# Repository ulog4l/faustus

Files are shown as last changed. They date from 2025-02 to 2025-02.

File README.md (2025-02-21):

# faustus

32 key [hummingbird](https://github.com/PJE66/hummingbird) adjacent keyboard, also taking inspiration from its variations, such as the [zilpzalp](https://github.com/kilipan/zilpzalp) thumb keys\
also credits to [ergogen](ergogen.cache.works) for simplifying the key placement tremendously\
exclusively supports choc switches, is choc spaced\
exclusively supports the [MIAO](https://github.com/kilipan/miao) controller and [FAK firmware](https://github.com/semickolon/fak)

this keyboard essentially restores the middle column to a hummingbird, making it possible to not combo for these keys and ruin your muscle memory for all other keyboards\
this is made possible by the miao having additional IO pins, removing the 30 key limit of the xiao that is used in the hummingbird

this keyboard uses BAV70 diodes

this pcb has some mounting tabs meant to provide freedom in designing cases, but sticking adhesive feet to the bottom is the lowest profile variant possible and therefore preferred



while i personally have working versions with both hotswap sockets and soldered switches i will of course not take any responsibility for the producteon files being functional, use them at your own risk

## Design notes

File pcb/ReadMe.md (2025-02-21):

provided are the kicad files as well as the scuffed freecad project used to construct the outline of the pcb and the ergogen code to generate the pcb(footprints and such are wrong though, it's just here as a reference)

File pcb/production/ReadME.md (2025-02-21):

no pcba, just solder the diodes by hands please!

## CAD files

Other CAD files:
pcb/raw.FCStd

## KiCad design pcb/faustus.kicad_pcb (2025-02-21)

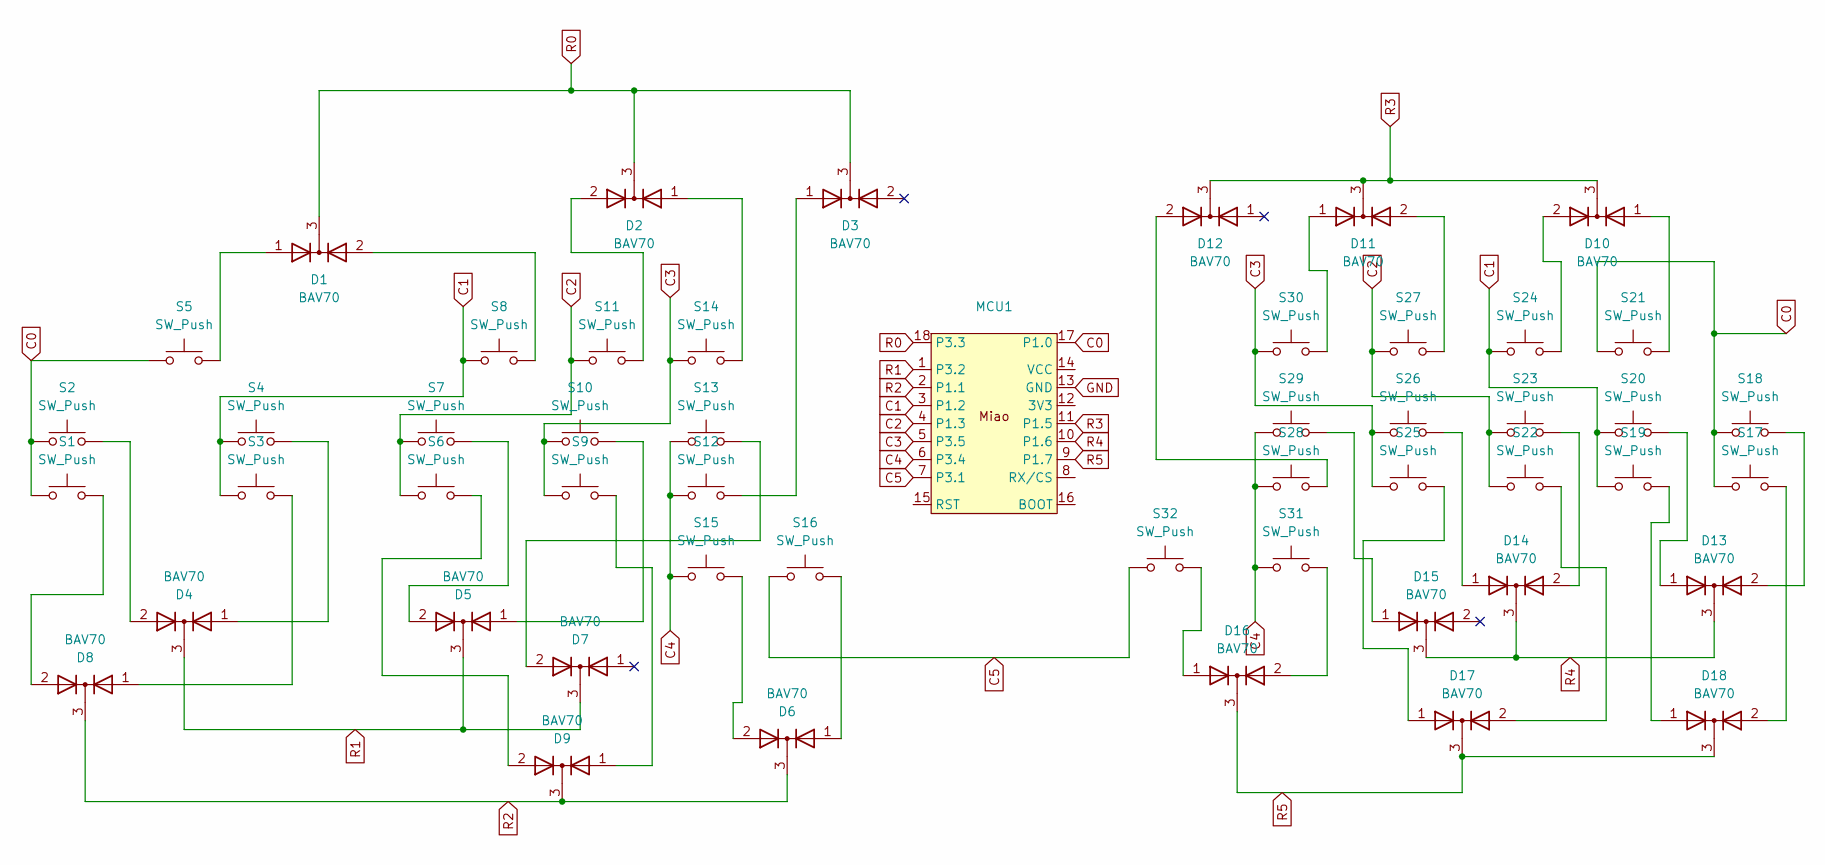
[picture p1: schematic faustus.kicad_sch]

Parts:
D1, D2, D3, D4, D5, D6, D7, D8, D9, D10, D11, D12, D13, D14, D15, D16, D17, D18: BAV70; SOT-23_Handsoldering
MCU1: Miao
S1, S2, S3, S4, S5, S6, S7, S8, S9, S10, S11, S12, S13, S14, S15, S16, S17, S18, S19, S20, S21, S22, S23, S24, S25, S26, S27, S28, S29, S30, S31, S32: SW_Push; SW_Kailh_socket_PG1350_optional

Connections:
C0: MCU1.17 (P1.0), S1.1, S2.1, S5.1, S17.1, S18.1, S21.1
C1: MCU1.3 (P1.2), S3.1, S4.1, S8.1, S19.1, S20.1, S24.1
C2: MCU1.4 (P1.3), S6.1, S7.1, S11.1, S22.1, S23.1, S27.1
C3: MCU1.5 (P3.5), S9.1, S10.1, S14.1, S25.1, S26.1, S30.1
C4: MCU1.6 (P3.4), S12.1, S13.1, S15.1, S28.1, S29.1, S31.1
C5: MCU1.7 (P3.1), S16.1, S32.1
GND: MCU1.13 (GND)
unnamed: D1.1 (A), S5.2
unnamed: D1.2 (A), S8.2
unnamed: D2.1 (A), S14.2
unnamed: D2.2 (A), S11.2
unnamed: D3.1 (A), S12.2
unnamed: D4.1 (A), S4.2
unnamed: D4.2 (A), S2.2
unnamed: D5.1 (A), S10.2
unnamed: D5.2 (A), S7.2
unnamed: D6.1 (A), S16.2
unnamed: D6.2 (A), S15.2
unnamed: D7.2 (A), S13.2
unnamed: D8.1 (A), S3.2
unnamed: D8.2 (A), S1.2
unnamed: D9.1 (A), S9.2
unnamed: D9.2 (A), S6.2
unnamed: D10.1 (A), S21.2
unnamed: D10.2 (A), S24.2
unnamed: D11.1 (A), S30.2
unnamed: D11.2 (A), S27.2
unnamed: D12.2 (A), S28.2
unnamed: D13.1 (A), S20.2
unnamed: D13.2 (A), S18.2
unnamed: D14.1 (A), S26.2
unnamed: D14.2 (A), S23.2
unnamed: D15.1 (A), S29.2
unnamed: D16.1 (A), S32.2
unnamed: D16.2 (A), S31.2
unnamed: D17.1 (A), S25.2
unnamed: D17.2 (A), S22.2
unnamed: D18.1 (A), S19.2
unnamed: D18.2 (A), S17.2
R0: D1.3 (K), D2.3 (K), D3.3 (K), MCU1.18 (P3.3)
R1: D4.3 (K), D5.3 (K), D7.3 (K), MCU1.1 (P3.2)
R2: D6.3 (K), D8.3 (K), D9.3 (K), MCU1.2 (P1.1)
R3: D10.3 (K), D11.3 (K), D12.3 (K), MCU1.11 (P1.5)
R4: D13.3 (K), D14.3 (K), D15.3 (K), MCU1.10 (P1.6)
R5: D16.3 (K), D17.3 (K), D18.3 (K), MCU1.9 (P1.7)

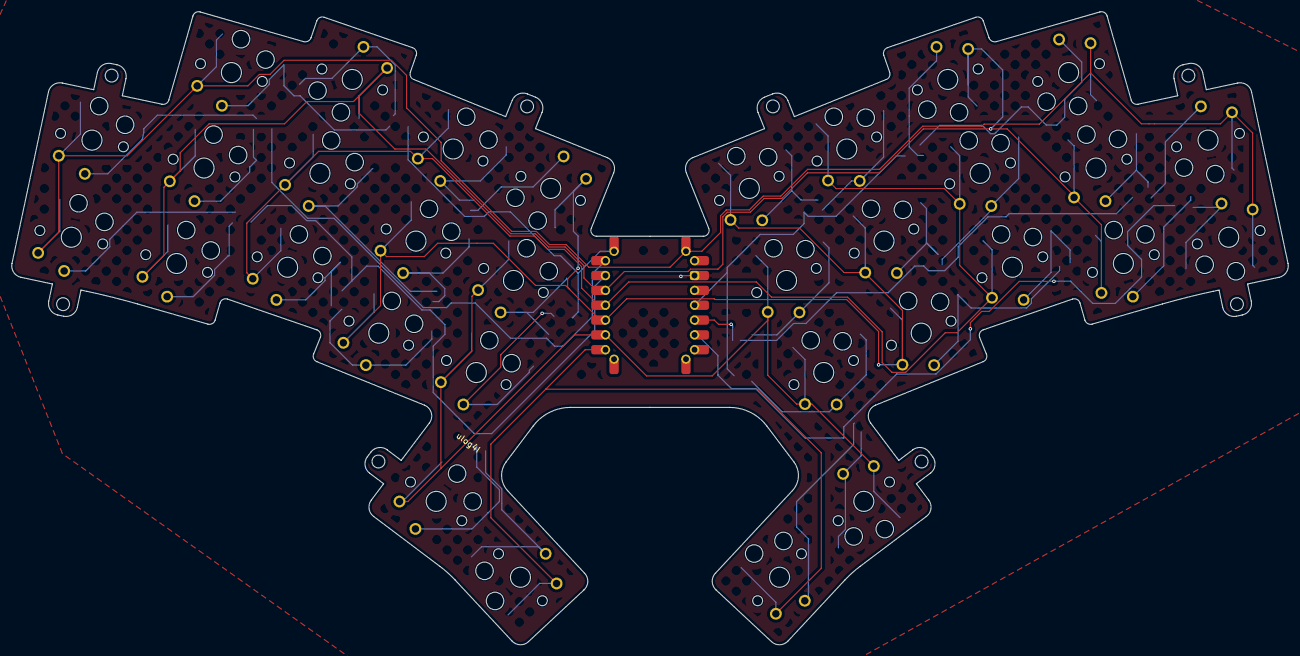
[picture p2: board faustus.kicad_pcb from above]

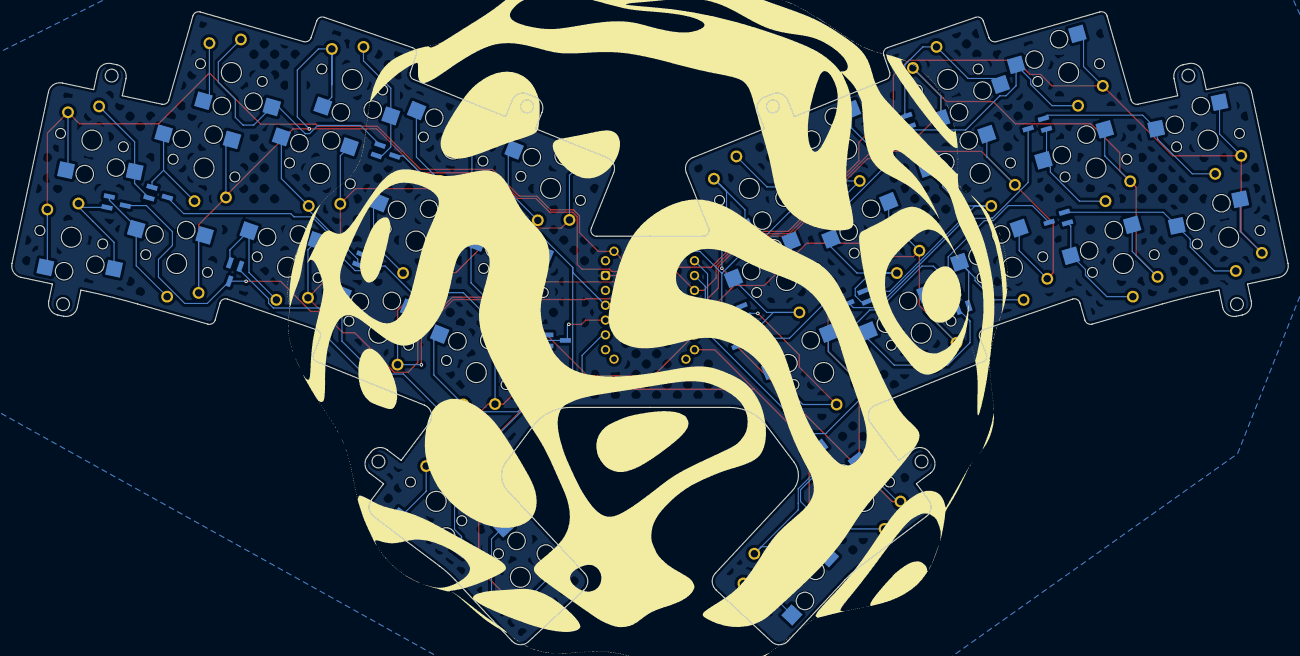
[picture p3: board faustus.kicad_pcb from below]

Board: 2 copper layers, 218.5 x 108.4 mm, 51 parts (18 on the bottom side), 44 nets.
